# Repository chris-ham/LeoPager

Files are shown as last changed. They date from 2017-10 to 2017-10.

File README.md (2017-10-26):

# LeoPager
Project that enables a web page interface running on a Raspberry Pi to send 433MHz pager messages using a LeoStick.<br />
The restaurant pagers that have been tested with this design are from AliExpress https://www.aliexpress.com/item/Guest-Coaster-Pager-System-for-order-taking-one-set-CTP320/32816821424.html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<br />

The above pager 'sets' each have a unique (as far as I know) identifier ie 1010100000111011 this is followed by the ID of the individual unit LSB first so pager 1 is 100000000 pager 2 is 010000000 etc<br />

The LeoStick https://www.freetronics.com.au/products/leostick#.WfGg4miCwUE receives messages via its USB interface and transmits the pager message out of a software serial port.<br />

Messages can also be received when the LeoStick is put into the correct mode.<br />

Message format is all human readable ASCII ie ?61010100000111011010000000\n<br />
+first byte is the number of times to send the message data - ie 9 sends message 9 times, ? sends it 15 times<br />
+Second byte is the delay between messages<br />
+rest of message contains the actual message to send. This message is an ASCII representation of binary ie 011011001...<br />
So ?61010100000111011010000000\n sends 1010100000111011010000000 15 times with a delay of 6 to the 2nd pager in bank 1010100000111011<br />

Sending the serial message 'GetCode' to the LeoStick will result in the 433MHz codes received by the receiver being echoed out the LeoStick's USB serial port. This will show the received message as 1010100000111011010000000 or such repeated several times. There will be the odd short message received however that is to be expected. These received messages  can be used to work out the bank number of the pager.<br />
  
Sending the serial message 'SendCode' will result in the 433MHz code reception being turned off<br />
The default is to not echo received codes<br />

The pagers can also be put into a 'learn code' mode if needed. See the scanned pager user manual in this hub for info on how to put them into learn mode.

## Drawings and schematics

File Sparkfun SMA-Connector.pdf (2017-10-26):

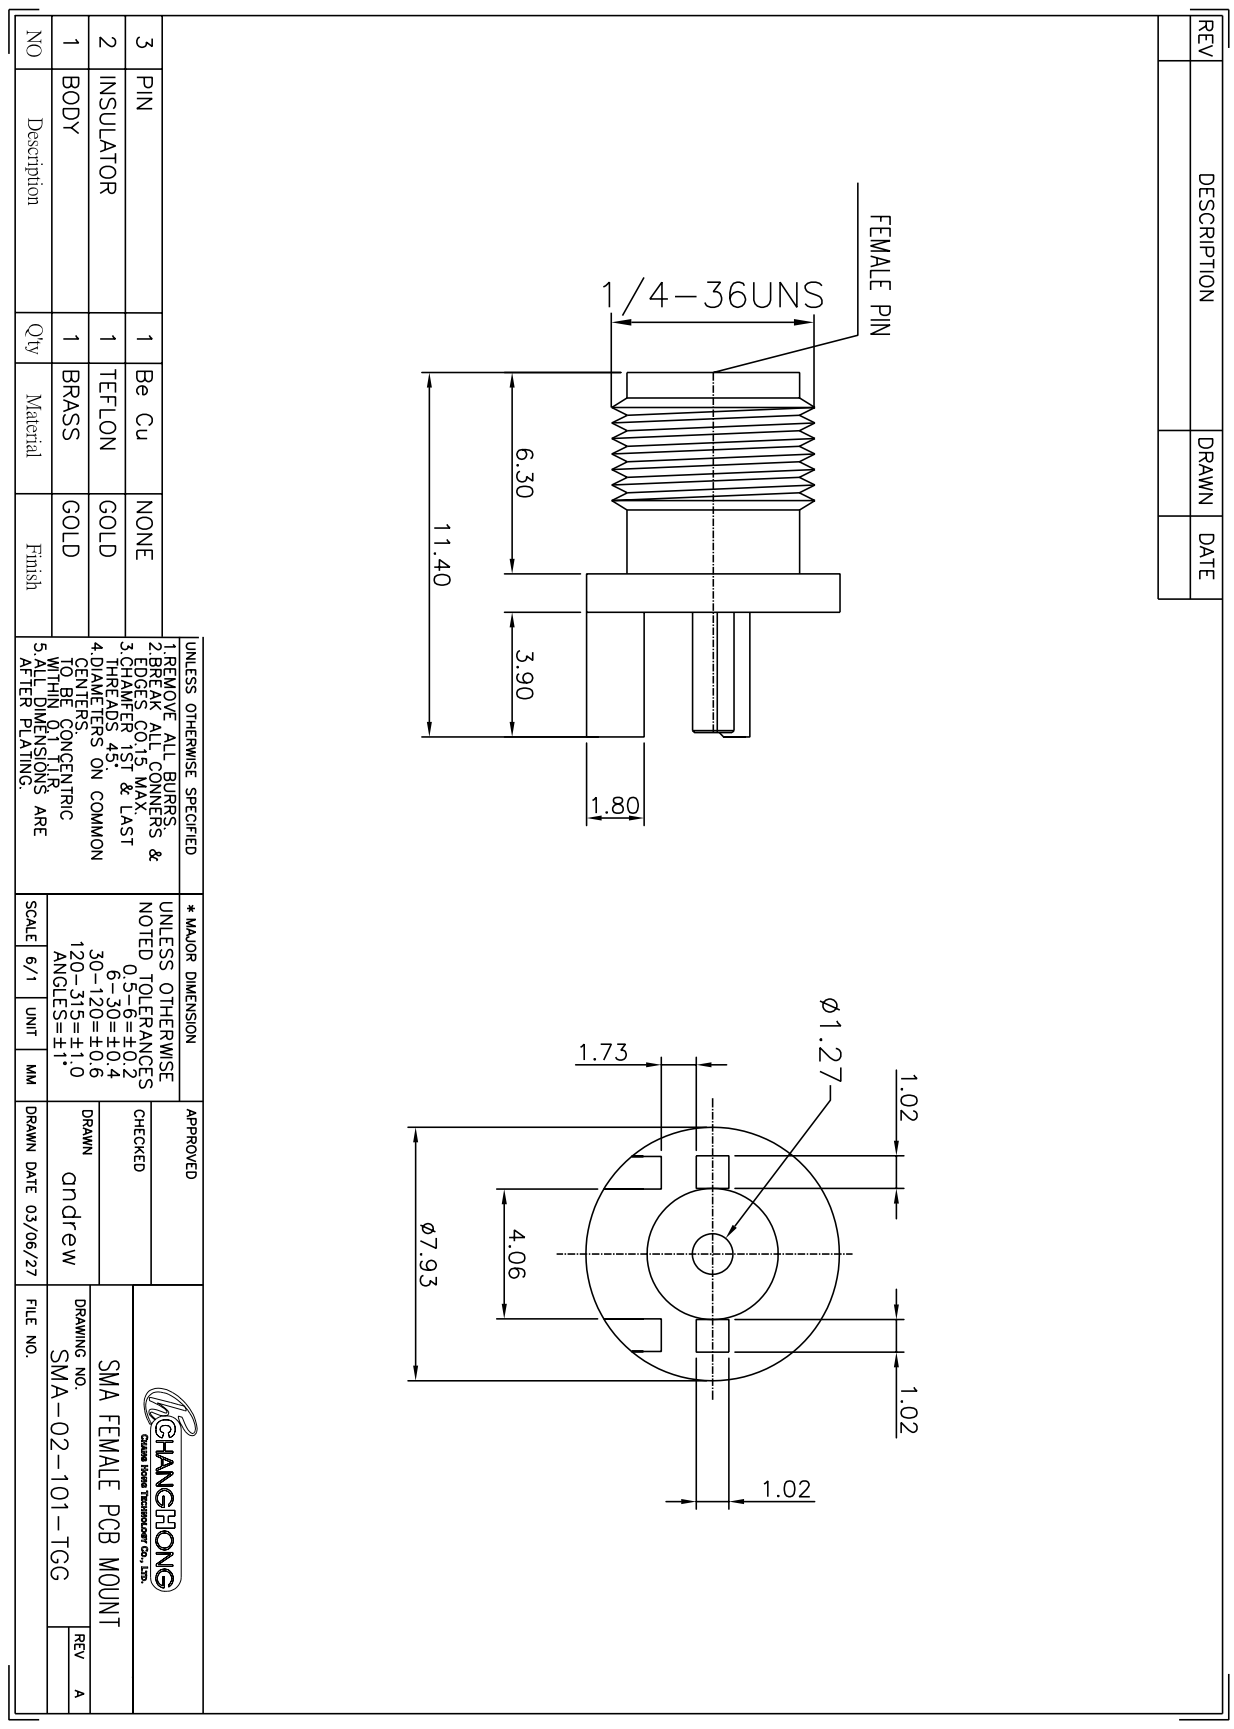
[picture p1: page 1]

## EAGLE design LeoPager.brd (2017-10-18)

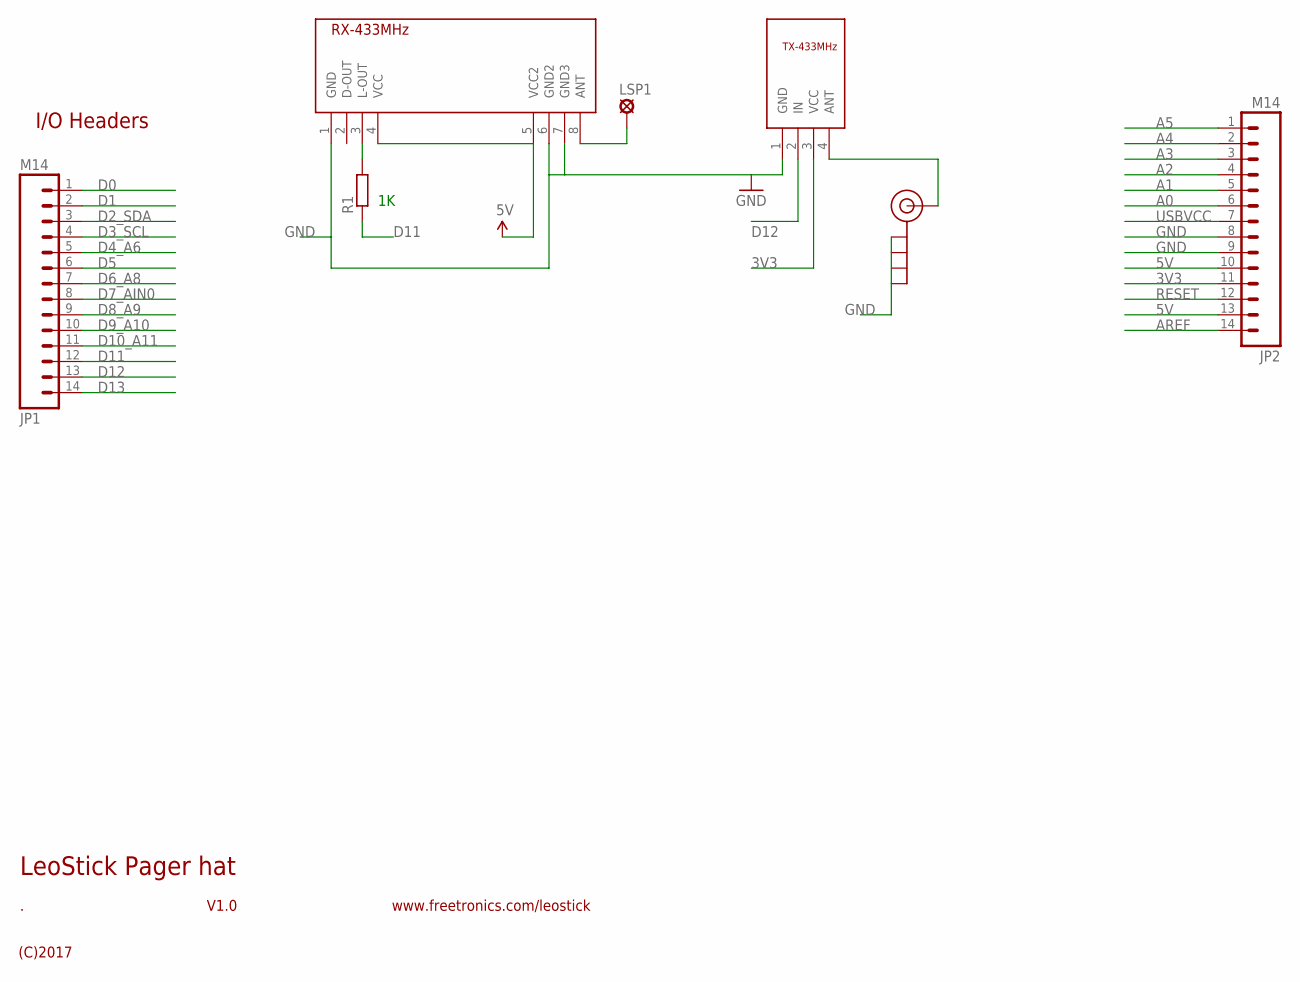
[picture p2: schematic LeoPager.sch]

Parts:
J$1: SMA_EDGE; SMA-EDGE
JP1, JP2: M14; 1X14
LSP1: LSP10
R1: R-EU_0204/7; 0204/7
RF-MODULE1: RX-433MHZ
RF-MODULE2: TX-433MHZ

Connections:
3V3: JP2.11, RF-MODULE2.3 (VCC)
5V: JP2.10, JP2.13, RF-MODULE1.4 (VCC), RF-MODULE1.5 (VCC2)
A0: JP2.6
A1: JP2.5
A2: JP2.4
A3: JP2.3
A4: JP2.2
A5: JP2.1
AREF: JP2.14
D0: JP1.1
D1: JP1.2
D2_SDA: JP1.3
D3_SCL: JP1.4
D4_A6: JP1.5
D5: JP1.6
D6_A8: JP1.7
D7_AIN0: JP1.8
D8_A9: JP1.9
D9_A10: JP1.10
D10_A11: JP1.11
D11: JP1.12, R1.1
D12: JP1.13, RF-MODULE2.2 (IN)
D13: JP1.14
GND: J$1.GND@0 (GND), J$1.GND@1 (GND), J$1.GND@2 (GND), J$1.GND@3 (GND), JP2.8, JP2.9, RF-MODULE1.1 (GND), RF-MODULE1.6 (GND2), RF-MODULE1.7 (GND3), RF-MODULE2.1 (GND)
unnamed: R1.2, RF-MODULE1.3 (L-OUT)
unnamed: J$1.SIG (SIGNAL), RF-MODULE2.4 (ANT)
unnamed: LSP1.MP, RF-MODULE1.8 (ANT)
RESET: JP2.12
USBVCC: JP2.7

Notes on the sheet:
I/O Headers
LeoStick Pager hat
V1.0
(C)2017
www.freetronics.com/leostick

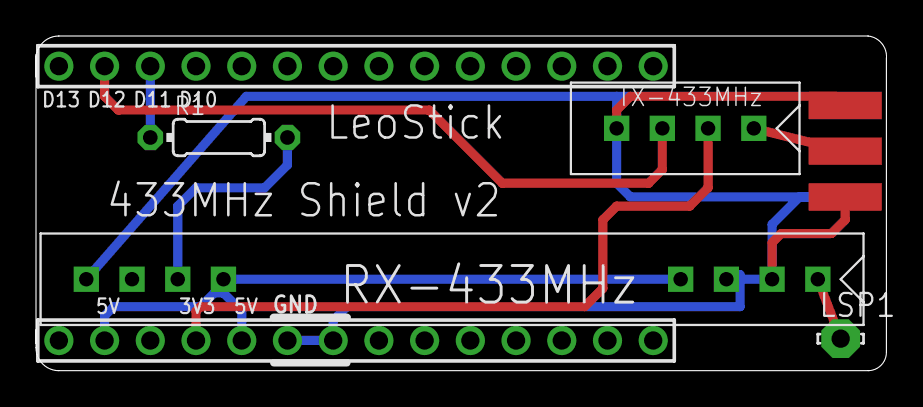
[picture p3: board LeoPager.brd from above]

Board: 2 copper layers, 47.3 x 18.6 mm, 7 parts (0 on the bottom side), 8 nets.

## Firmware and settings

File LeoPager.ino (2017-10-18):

/*
This Arduino App is designed to allow an external device to send (and receive) properly formatted
messages to bar style vibrating 433MHz pagers. The message payload is sent to the LeoStick as an RS232 string
via the arduino's USB serial port.

The reason for using a LeoStick in this way is to allow transmission of the pager data
without the waveform being corrupted by other embedded processes.

The 'pay load' is sent out of the Arduino's RS232 port after each 'bit' is converted
to an ASCII char that will give the correct vaveform for the vibrating pager to recognise. 
 
**Board
Arduino LeoStick 2560

**Pager banks
*WHITE  1010100000111011
*YELLOW 1001000000000111
*RED    0010111100011011
*BLUE   0010101100111011
*GREEN  1010010000111011

** .... message format
+first byte is the number of times to send the message data
+Second byte is the delay between messages
+rest of message contains the actual message to send. This message is binary ie 011011001...

Sending the serial message 'GetCode' to the LeoStick will result in the 433MHz codes received
  by the receiver being echoed out the USB serial port
Sending the serial message 'SendCode' will result in the 433MHz code reception being turned off
The default is to not echo received codes

*/


//Pager block
#include <SoftwareSerial.h>
String PagerMsg;
bool NewLine = true;

//set up the software serial port that will be used to transmit the 433Mhz
//codes to the pagers. A Jaycar ZW3100 is used as the RF module
//https://www.jaycar.co.nz/wireless-modules-transmitter-433mhz/p/ZW3100
//SoftwareSerial used so we can invert the polarity of the data being set to teh RF module
//   this saves having to use a hardware inverter.
//In the setup below we have Rx, Tx, Inv
//Pin 12 is connected to Rx
//Pin 11 is connected to the Transmitter
//Signal is inverted
#define TxIsOnPin 12
#define RxIsOnPin 11
#define Inverted 1
SoftwareSerial mySerial(RxIsOnPin, TxIsOnPin, Inverted);

int BitCount = 0;
byte one = 0x80;
byte zero = 0xFC;
String currentLine; 
int queryStringStart;
int queryStringEnd;

// pins for the LEDs:
const int redPin = 13;
const int greenPin = 9;
const int bluePin = 10;

int incomming = '.';
String received = "";
unsigned long previousMillis = 0;
unsigned long currentMillis = 0;
const long interval = 3500;
int Mode = 0;   //transmit

char inChar = '0';

//************************************************
void setup() {
  pinMode(redPin, OUTPUT);
  pinMode(greenPin, OUTPUT);
  pinMode(bluePin, OUTPUT);

  analogWrite(redPin, 127);
  analogWrite(greenPin, 0);
              
  // Open serial communications:
  Serial.begin(9600);
  Serial.println("Pager Transmiter");   
  
  // set the data rate for the SoftwareSerial port
  mySerial.begin(9600);
}

//************************************************
//sends the data with the correct waveform out the serial port
//each 'bit' is represented by a 'zero' or 'one' character being
//sent out of the RS232 port. The reason for converting the 'zero' and 'one'
//is to emulate manchester encoding https://en.wikipedia.org/wiki/Manchester_code
//The LSB of the pager number is sent first
void sendData(String data){
  char ID = 0;
  int Count = data.length();
  for (int i=0; i<Count; i++){
    ID = data[i];
    if (ID == '0'){
      mySerial.write(zero);
    }else{
      mySerial.write(one);
    }
  }
}

//************************************************
//Sends the msg the requested number of times
//   with set delay between each data burst
void sendMsg(String toSend){
  int NumTimes = toSend[0] - '0';
  int aDelay = toSend[1] - '0';
  for (int i=0; i<NumTimes; i++){
    sendData(toSend.substring(2,27));
    delay(aDelay);
  }
}

//************************************************
//************************************************
//************************************************
void loop() {

  //+++++++++++++++++ deal with received data +++++++++++
  //get received 433MHz data and send it to the USB serial port
  //this will only happen when we have set the Arduino to read mode.
  if (mySerial.available() > 0){
    currentMillis = micros();
    if (currentMillis - previousMillis >= interval) {
      if ((BitCount == 24) && (Mode == 1)){
        Serial.println(received);
      }
      BitCount = 0;
      received = "";
    }else{
      BitCount ++;
    };
    previousMillis = currentMillis;

    incomming = mySerial.read();
    if (incomming == 0xFC){
      received = received + '0';
    };  
    if (incomming == 0x80){
      received = received + '1';
    }; 
  }

  //+++++++++++++++++ send data burst without interruption +++++++++++
  // if there's any serial available, read it
  //and transmit it when the time comes
  while (Serial.available() > 0) {
    inChar = Serial.read();

    //if we get \r set led to red to indicate error
    if (inChar == '\r'){
      Serial.println(currentLine);
      currentLine = "";      
    }
    
    //only transmit on \n
    if (inChar == '\n'){
      PagerMsg = currentLine;
      if (PagerMsg == "GetCode"){
        //turn on 433Mhz RX line and Tx line off
        analogWrite(greenPin, 127);
        analogWrite(redPin, 0);
        Mode = 1;  //receive  
      }else{
         if (PagerMsg == "SendCode"){
            //turn off 433MHz Rx line and Tx line on
            analogWrite(greenPin, 0);
            analogWrite(redPin, 127);
            Mode = 0; //transmit
          }else{
            sendMsg(PagerMsg);
            analogWrite(bluePin, 0);
          }
      }      
      Serial.println(currentLine);
      currentLine = "";
      analogWrite(bluePin, 0);
    }
    
    //only add character if it is not CR or LF
    if ((inChar != '\r') && (inChar != '\n')){
      currentLine += inChar;
    }
  }

}

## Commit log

2017-10-18 Gerber files for Leostick hat v2
    Full set of Gerber files that are used to create the 433MHz hat for the Arduino Leostick hat
2017-10-18 Autodesk Eagle files for LeoPager
    The PCB was designed using Autodesk's Eagle CAD software.
    [LeoPager.brd, LeoPager.sch]
2017-10-18 Arduino software
    Application that runs on the Arduino Leostick that transmits the 433MHz pager message
2017-10-26 Add files via upload
    Added data sheets for tested 433MHZ RX and TX units and SMA connector
2017-10-26 Add files via upload
    Added user manual for Wireless Calling System as it is supplied with the pagers
